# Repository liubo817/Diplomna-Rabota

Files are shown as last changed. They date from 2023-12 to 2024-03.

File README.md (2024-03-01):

# БОБКА - Био-Оптимизатор за Безопасна Костенуркова Атмосфера
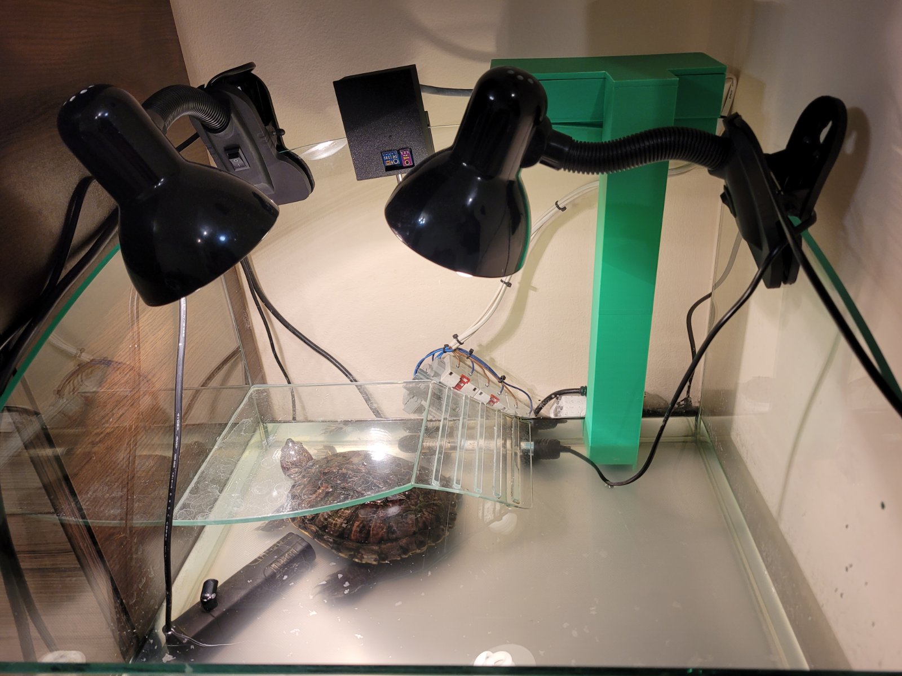
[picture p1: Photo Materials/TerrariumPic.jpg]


## **Описание**
Дипломната работа представя успешната разработка на вградена система, предназначена за наблюдение и управление на терариум за земноводни костенурки. Проектът обхваща иновативен хардуер и софтуер, които съчетават общоприети технологии.

## [Документация](https://docs.google.com/document/d/1n0dCljN07w4FLzlgteggXlk4XJQZPIcb2BojlvGgTRA/edit) ##

## **Създател:**
- **[Любомир Станев](https://github.com/liubo817)**

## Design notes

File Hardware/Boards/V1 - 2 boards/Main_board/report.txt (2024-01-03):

Info: Updated footprint U5 (Diplomna:5pin_holes): : (no changes)
Info: Updated footprint REF** (MountingHole:MountingHole_2.2mm_M2_DIN965_Pad_TopBottom): : (no changes)
Info: Updated footprint REF** (Resistor_SMD:R_0603_1608Metric_Pad0.98x0.95mm_HandSolder): : (no changes)
Info: Updated footprint REF** (Resistor_SMD:R_1206_3216Metric): : (no changes)
Info: Updated footprint REF** (Resistor_SMD:R_0603_1608Metric_Pad0.98x0.95mm_HandSolder): : (no changes)
Info: Updated footprint R1 (Resistor_SMD:R_1206_3216Metric): : (no changes)
Updated footprint U4 (Diplomna:light sensor): : OK
Updated footprint U3 (Diplomna:DS18B20_3dmodel): : OK
Updated footprint U2 (Diplomna:DS18B20_3dmodel): : OK
Info: Updated footprint REF** (Resistor_SMD:R_0603_1608Metric_Pad0.98x0.95mm_HandSolder): : (no changes)
Info: Updated footprint REF** (Package_TO_SOT_SMD:SOT-23): : (no changes)
Updated footprint U4 (Diplomna:DS18B20_3dmodel): : OK
Info: Updated footprint REF** (Resistor_SMD:R_0603_1608Metric_Pad0.98x0.95mm_HandSolder): : (no changes)
Updated footprint U1 (Diplomna:MODULE_ESP32-DEVKITC): : OK
Info: Updated footprint REF** (Diplomna:3pin_holes): : (no changes)
Info: Updated footprint REF** (MountingHole:MountingHole_2.2mm_M2_DIN965_Pad_TopBottom): : (no changes)
Updated footprint U4 (Diplomna:light sensor): : OK
Updated footprint U6 (Diplomna:DS18B20_3dmodel): : OK
Info: Updated footprint REF** (Resistor_SMD:R_0603_1608Metric_Pad0.98x0.95mm_HandSolder): : (no changes)

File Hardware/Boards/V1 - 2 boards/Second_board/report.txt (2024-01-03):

Info: Processing symbol 'J1:'.
Info: Processing symbol 'K1:EC2-5NU:RELAY_EC2-5NU'.
Info: Processing symbol 'R1:Resistor_SMD:R_1206_3216Metric'.
Info: Processing symbol 'U1:Diplomna:5pin_holes'.
Info: Processing symbol 'U2:Diplomna:light sensor'.
Info: Processing symbol 'U3:Diplomna:DS18B20_3dmodel'.
Warning: No net found for symbol U2 pin BASE.
Warning: No net found for symbol U2 pin COLLECTOR.
Warning: No net found for symbol U2 pin EMITTER.
Error: Cannot add J1 (no footprint assigned).
Error: Cannot add K1 (footprint 'EC2-5NU:RELAY_EC2-5NU' not found).
Error: U2 pad 3 not found in Diplomna:light sensor.
Error: U2 pad 2 not found in Diplomna:light sensor.
Error: U2 pad 1 not found in Diplomna:light sensor.

Info: Total warnings: 3, errors: 5.

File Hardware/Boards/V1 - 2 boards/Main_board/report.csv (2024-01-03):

Net Code | Net Name | Pad Count | Via Count | Via Length | Track Length | Die Length | Net Length | F.Cu | B.Cu
001 | +5V | 2 | 1 | 1.6000 mm | 36.9458 mm | 0.0000 mm | 38.5458 mm | 30.4289 mm | 6.5168 mm
002 | /Temp_out | 2 | 4 | 6.4000 mm | 106.2442 mm | 0.0000 mm | 112.6442 mm | 62.6944 mm | 43.5498 mm
003 | GND | 5 | 8 | 12.8000 mm | 158.6912 mm | 0.0000 mm | 171.4912 mm | 73.4497 mm | 85.2415 mm
004 | +3.3V | 4 | 2 | 3.2000 mm | 65.8150 mm | 0.0000 mm | 69.0150 mm | 8.3388 mm | 57.4762 mm
005 | /UV_out | 2 | 4 | 6.4000 mm | 91.8094 mm | 0.0000 mm | 98.2094 mm | 48.8913 mm | 42.9182 mm
006 | /Brightness_out | 2 | 4 | 6.4000 mm | 94.4588 mm | 0.0000 mm | 100.8588 mm | 51.4313 mm | 43.0275 mm
007 | /UV_ref | 2 | 3 | 4.8000 mm | 105.0883 mm | 0.0000 mm | 109.8883 mm | 61.1538 mm | 43.9345 mm
008 | /Water_temp_out | 3 | 3 | 4.8000 mm | 72.5599 mm | 0.0000 mm | 77.3599 mm | 26.5573 mm | 46.0026 mm
009 | /Turbidity_out | 2 | 0 | 0.0000 mm | 10.9145 mm | 0.0000 mm | 10.9145 mm | 0.0000 mm | 10.9145 mm
018 | /Water_level_out | 2 | 1 | 1.6000 mm | 80.7209 mm | 0.0000 mm | 82.3209 mm | 43.5137 mm | 37.2073 mm
040 | /Water_Level_Power | 2 | 3 | 4.8000 mm | 125.5482 mm | 0.0000 mm | 130.3482 mm | 65.5681 mm | 59.9801 mm

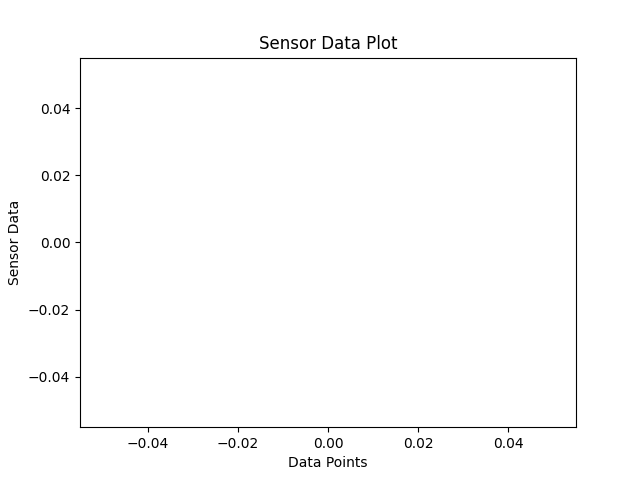
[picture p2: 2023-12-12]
Software/static/images/plot.png

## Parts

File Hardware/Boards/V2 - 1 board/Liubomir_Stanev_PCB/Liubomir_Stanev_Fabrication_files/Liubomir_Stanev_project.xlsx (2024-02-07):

Id | Designator | Footprint | Quantity | Designation
1 | U5 | 3pin_holes | 1 | DS18B20-water | ДА
2 | R1,R2 | R_Axial_DIN0309_L9.0mm_D3.2mm_P12.70mm_Horizontal | 2 | 2.2k | ДА
3 | J4,J5,J1,J2 | connector_3p | 4 | Conn_01x03_Pin | ?
4 | U2 | 3pin_holes | 1 | TEMT6000 | ДА
5 | U8 | connector_6p | 1 | Relay module | ДА
6 | U7 | MODULE_ESP32-DEVKITC | 1 | ESP32 | ДА
7 | J6,J3 | connector_2p | 2 | Conn_01x02_Pin | ДА
8 | U6 | 3pin_holes | 1 | Water Level Sensor | ДА
9 | U3 | 3pin_holes | 1 | DS18B20-air | ДА
10 | U4 | 3pin_holes | 1 | Turbidity sensor | ДА
11 | U1 | 5pin_holes | 1 | GY-8511 UV sensor | ДА
12 |  | Винтове за крепежни отвори | 4 | За сензора | НЕ
13 |  | Винтове за крепежни отвори | 8 | За платките | НЕ

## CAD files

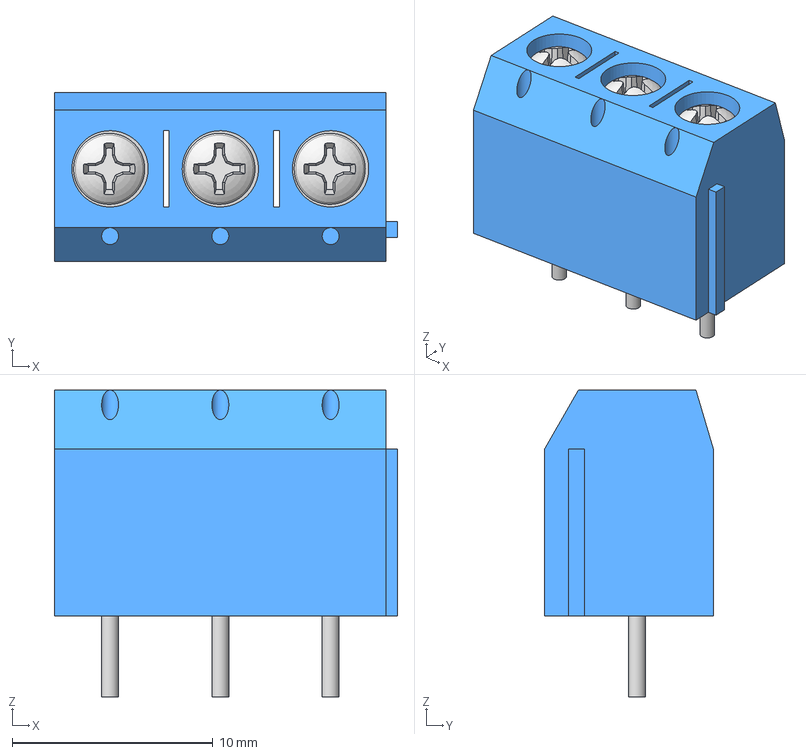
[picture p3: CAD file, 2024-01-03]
Hardware/Libraries and 3D models/3p_con/connector_3p v2.step
17.1 x 8.41 x 15.3 mm

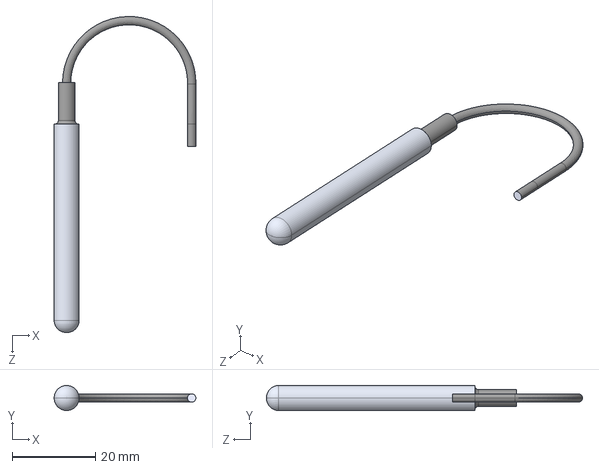
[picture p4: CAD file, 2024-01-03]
Hardware/Libraries and 3D models/Ds18B20/ds18b20.STEP
34.0 x 6.00 x 75.8 mm

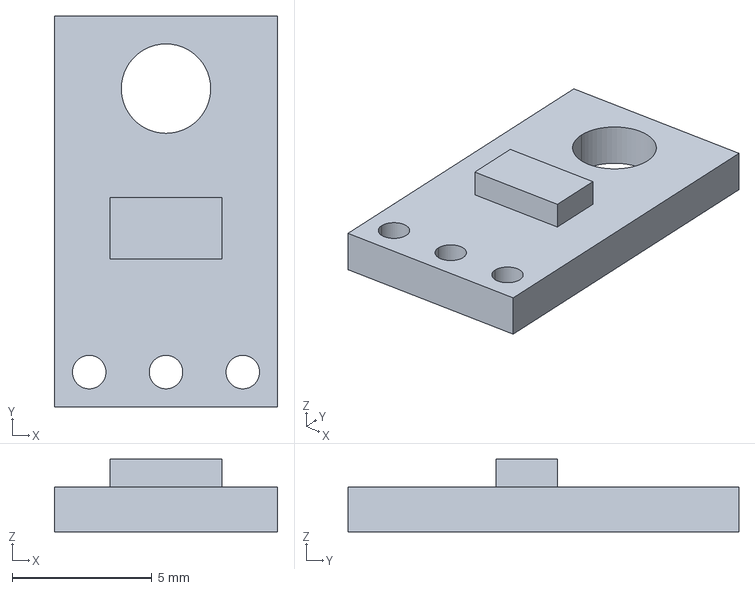
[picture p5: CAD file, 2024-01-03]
Hardware/Libraries and 3D models/Light_Sensor/TEMT6000.stp
8.00 x 14.0 x 2.60 mm

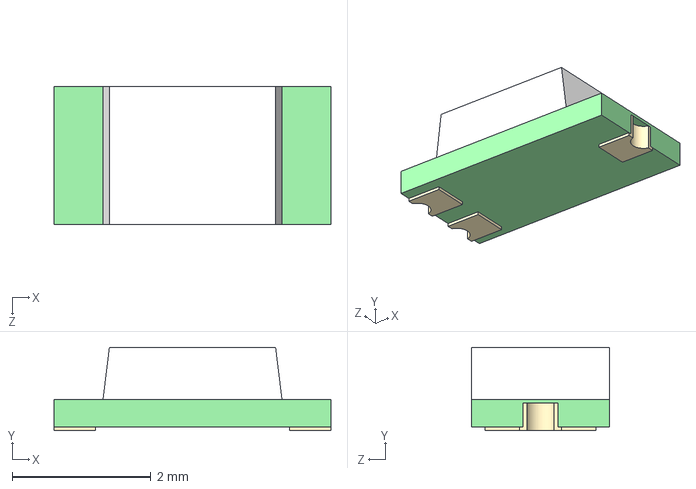
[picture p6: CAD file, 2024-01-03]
Hardware/Libraries and 3D models/TEMT6000/TEMT6000X01--3DModel-STEP-56544.STEP
4.00 x 1.20 x 2.00 mm

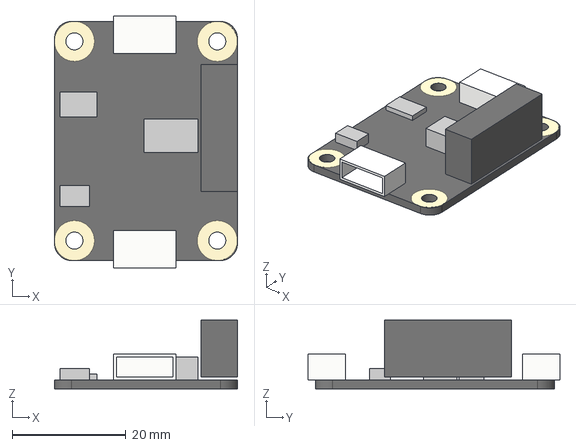
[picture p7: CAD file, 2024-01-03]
Hardware/Libraries and 3D models/Turbidity_sensor/Analog Isolator DF Robot v1.step
32.1 x 44.3 x 12.1 mm

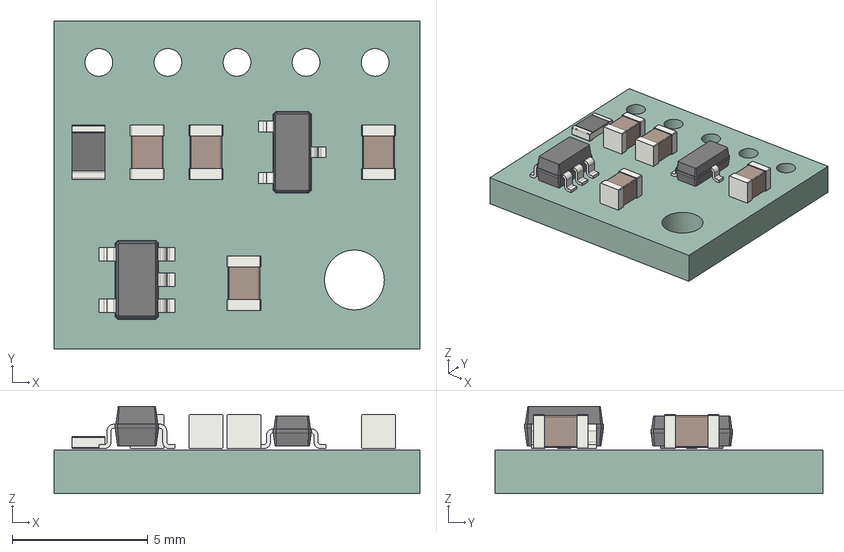
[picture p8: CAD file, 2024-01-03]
Hardware/Libraries and 3D models/UV/uv.step
13.5 x 12.1 x 3.20 mm
uv PCB

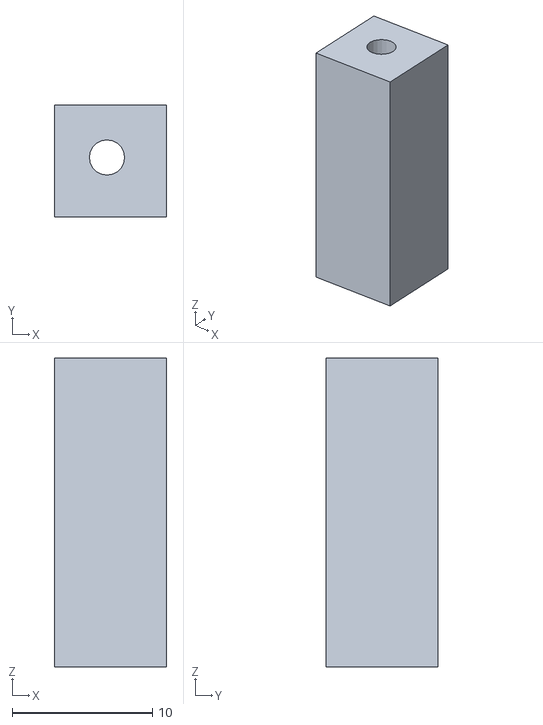
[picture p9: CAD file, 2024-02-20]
Mechanical details/Dist.vtulka.stl
8.00 x 8.00 x 22.0

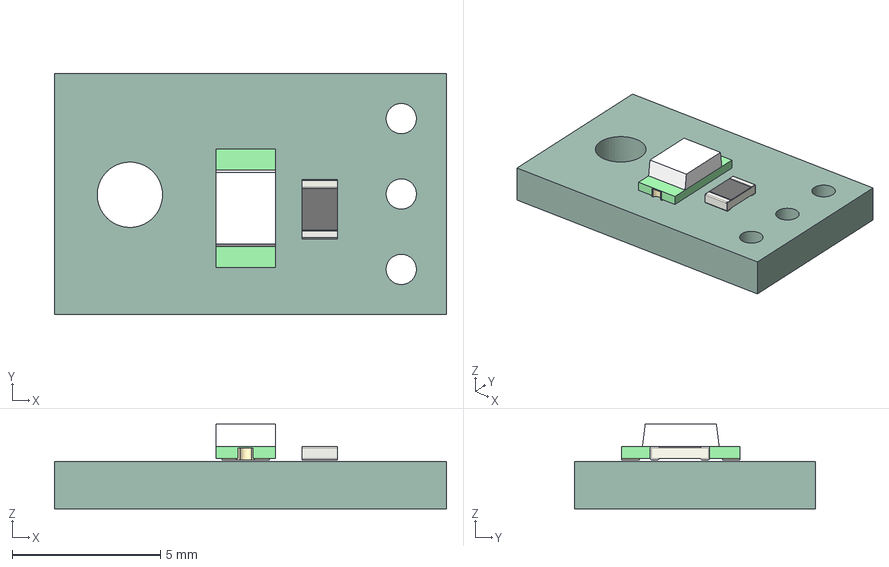
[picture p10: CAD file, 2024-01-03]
Hardware/Libraries and 3D models/TEMT6000/temt6000.step
13.2 x 8.13 x 2.85 mm
temt6000 PCB

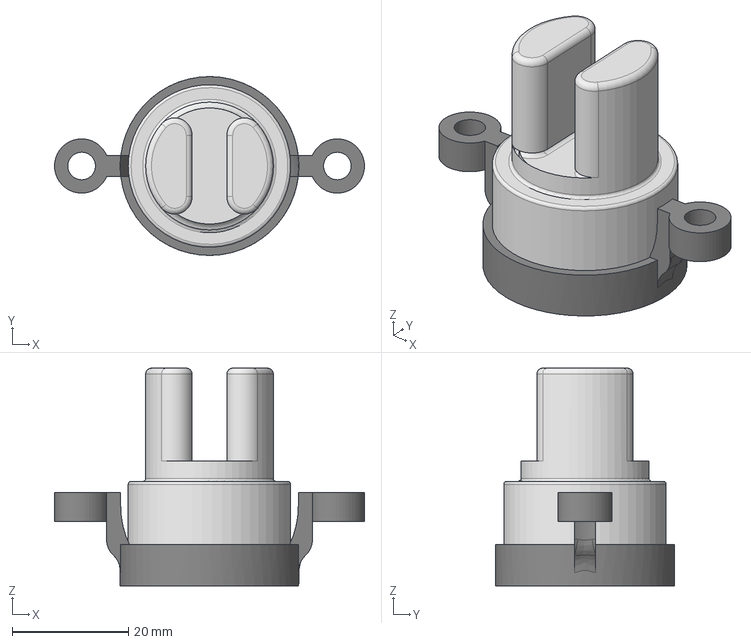
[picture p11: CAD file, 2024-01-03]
Hardware/Libraries and 3D models/Turbidity_sensor/Turbidity Sensor v1.step
53.4 x 30.8 x 37.5 mm

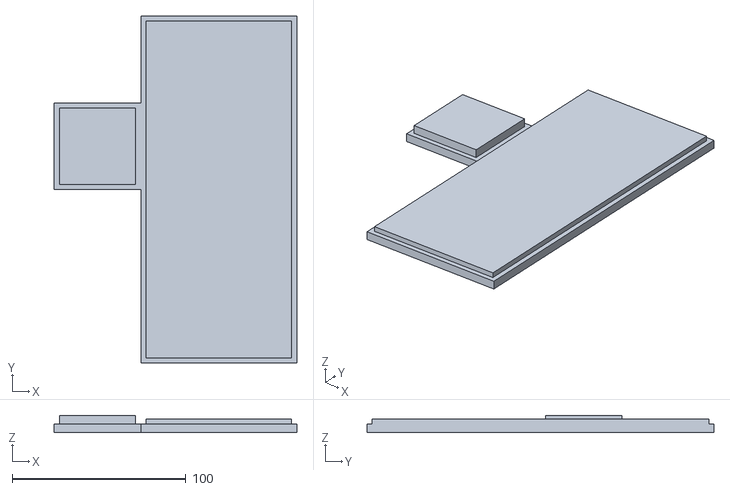
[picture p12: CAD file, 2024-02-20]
Mechanical details/TopSide_BigBox.stl
140.0 x 200.0 x 10.0

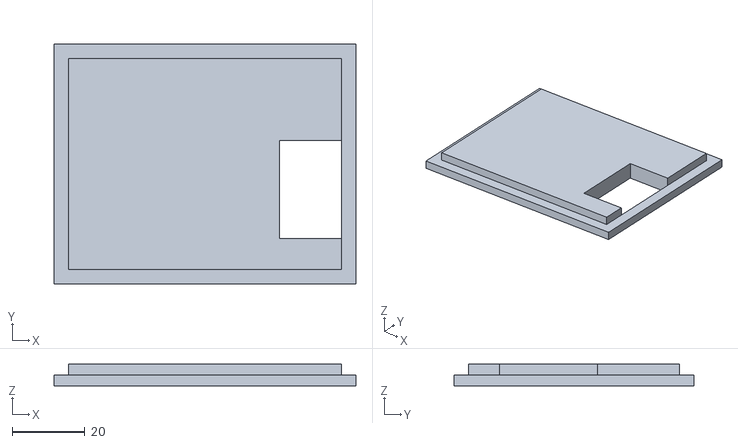
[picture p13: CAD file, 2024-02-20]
Mechanical details/TopSide_SmallBox.stl
83.0 x 66.0 x 6.00

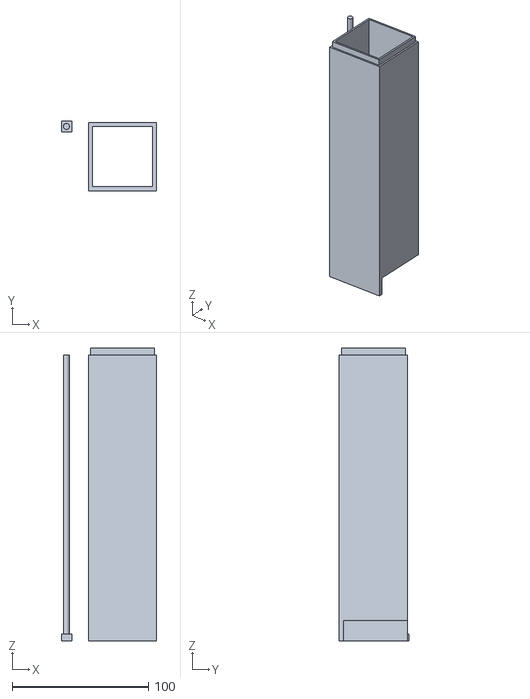
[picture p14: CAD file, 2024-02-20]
Mechanical details/Kolona2.stl
70.0 x 51.0 x 215.0

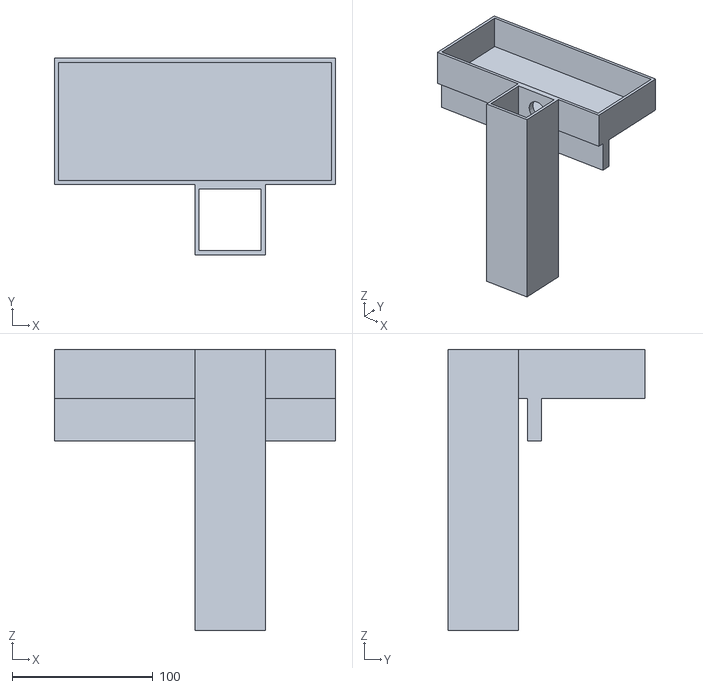
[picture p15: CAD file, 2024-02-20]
Mechanical details/BigBox.stl
200.0 x 140.0 x 200.0

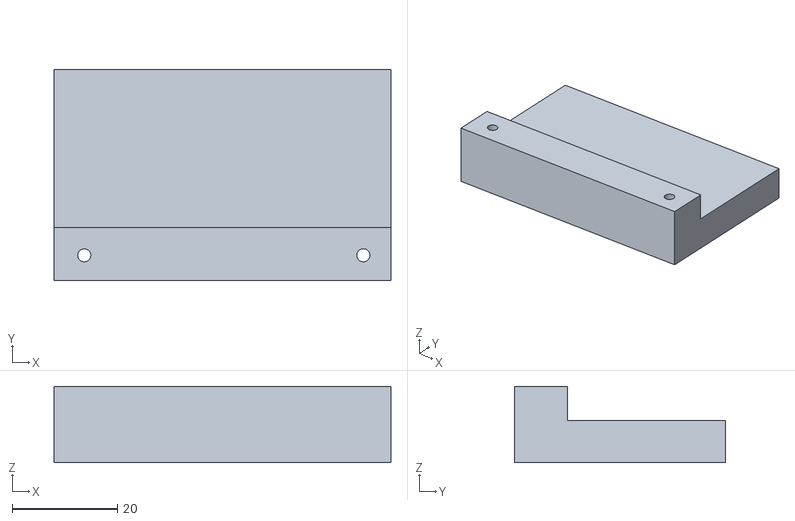
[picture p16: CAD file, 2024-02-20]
Mechanical details/G-figure.stl
64.0 x 40.0 x 14.5

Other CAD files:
Mechanical details/SmallBox.stl
Hardware/Libraries and 3D models/3p_con/connector_3p v1.step
Hardware/Libraries and 3D models/3p_con/connector_3p v1.f3d

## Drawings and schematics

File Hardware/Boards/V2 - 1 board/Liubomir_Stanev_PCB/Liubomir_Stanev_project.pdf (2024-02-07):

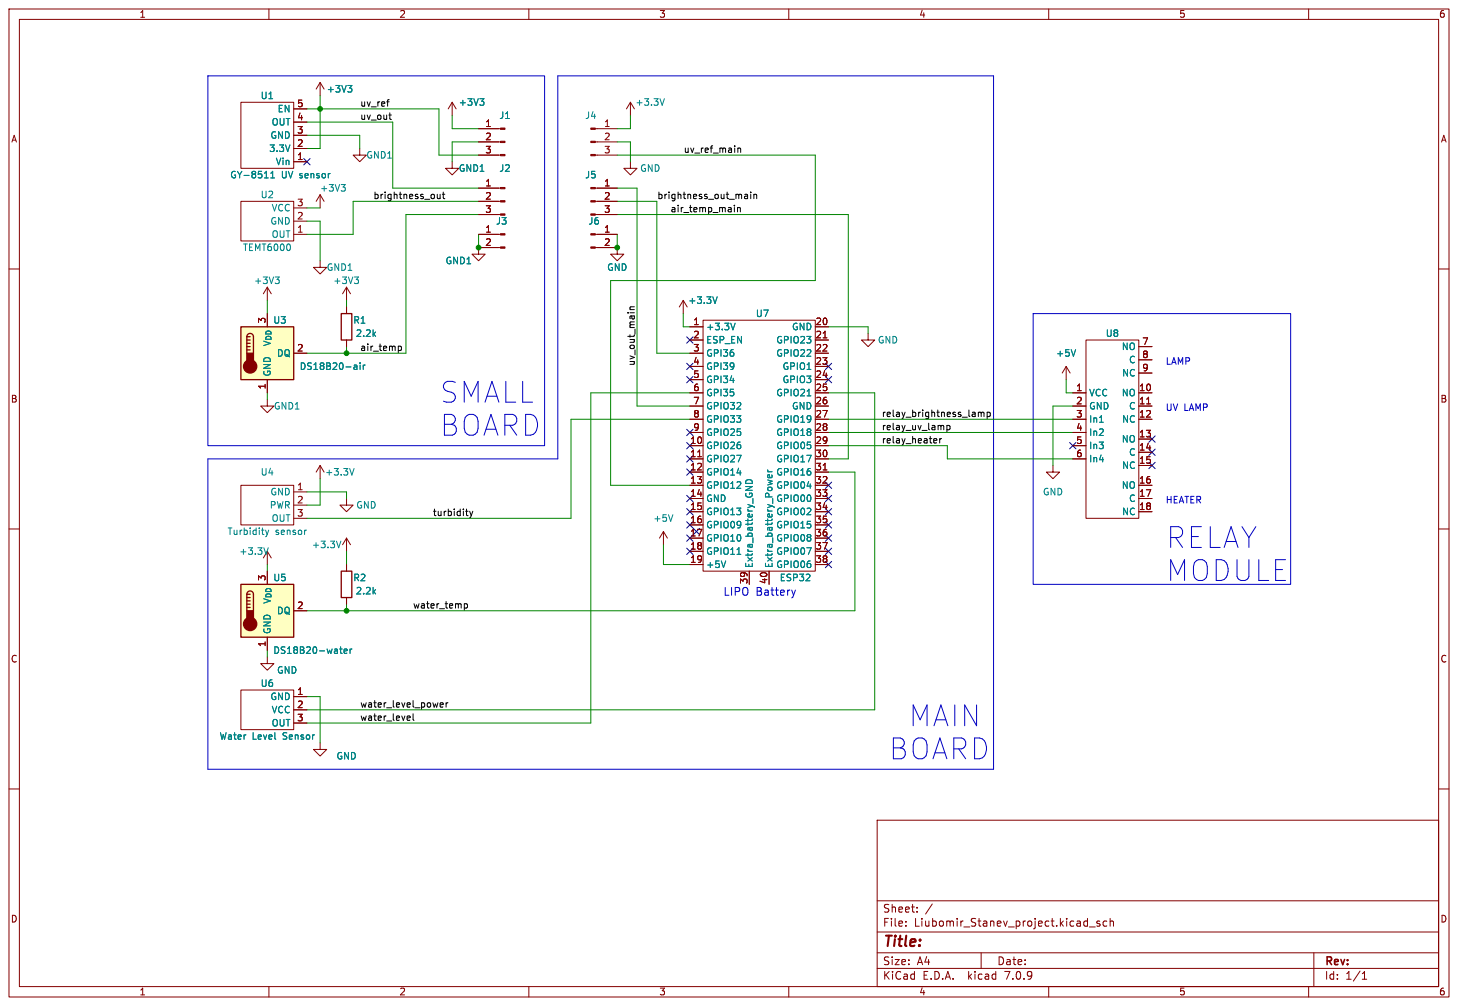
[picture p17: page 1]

Id: 1/1 Title: File: Liubomir_Stanev_project.kicad_sch Sheet: /

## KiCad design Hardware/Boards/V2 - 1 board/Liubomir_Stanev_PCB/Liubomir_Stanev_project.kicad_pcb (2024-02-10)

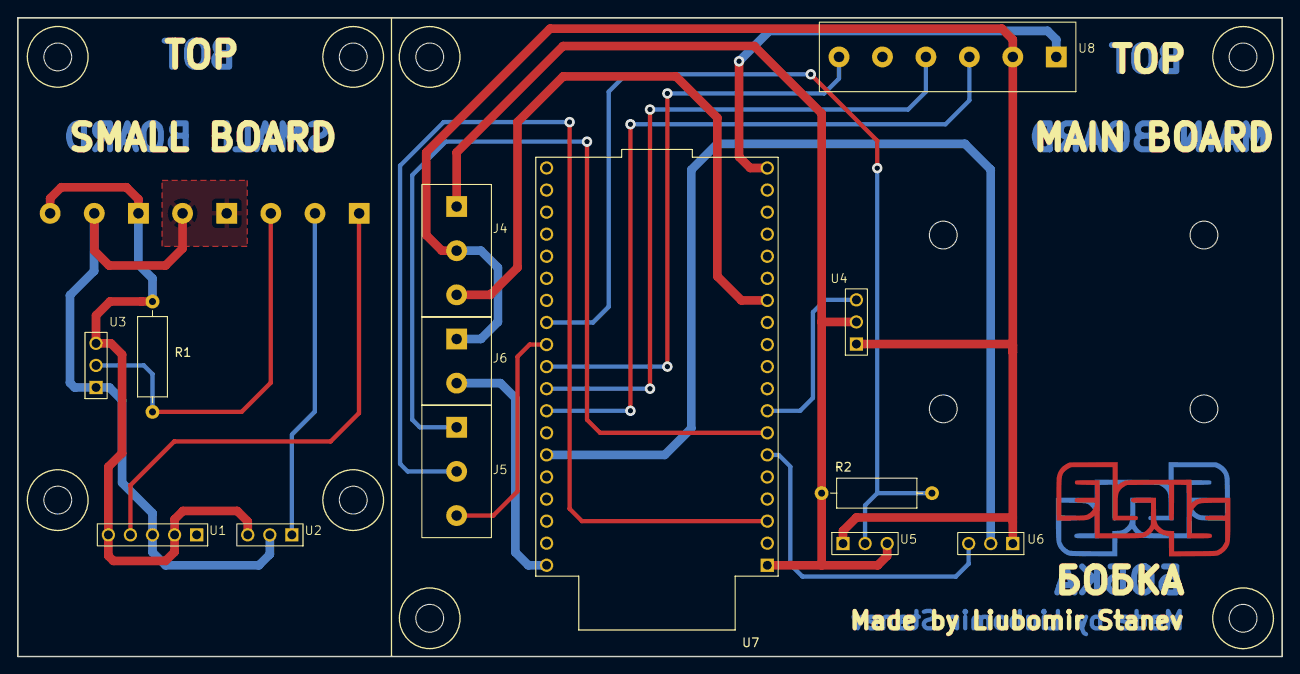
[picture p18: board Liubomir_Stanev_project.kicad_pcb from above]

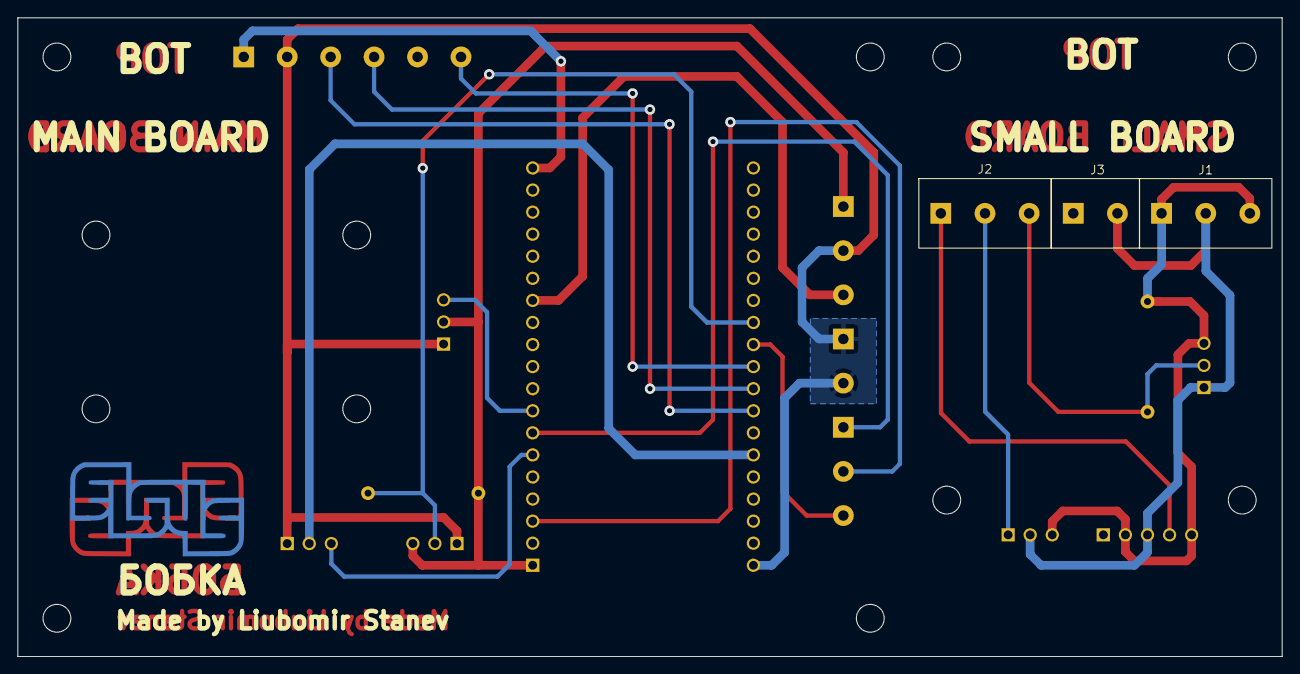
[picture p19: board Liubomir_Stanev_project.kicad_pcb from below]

Board: 2 copper layers, 145.5 x 73.5 mm, 16 parts (3 on the bottom side), 19 nets.

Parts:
J1, J2, J4, J5: Conn_01x03_Pin; connector_3p
J3, J6: Conn_01x02_Pin; connector_2p
R1, R2: 2.2k; R_Axial_DIN0309_L9.0mm_D3.2mm_P12.70mm_Horizontal
U1: GY-8511 UV sensor; 5pin_holes
U2: TEMT6000; 3pin_holes
U3: DS18B20-air; 3pin_holes
U4: Turbidity sensor; 3pin_holes
U5: DS18B20-water; 3pin_holes
U6: Water Level Sensor; 3pin_holes
U7: ESP32; MODULE_ESP32-DEVKITC
U8: Relay module; connector_6p

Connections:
+3.3V: J4.1, R2.1, U4.2 (PWR), U5.3 (V_{DD}), U7.1 (+3.3V)
+3V3: J1.1, J1.3, R1.1, U1.2 (3.3V), U1.5 (EN), U2.3 (VCC), U3.3 (V_{DD})
+5V: U7.19 (+5V), U8.1 (VCC)
/air_temp: J2.3, R1.2, U3.2 (DQ)
/air_temp_main: J5.3, U7.30 (GPIO17)
/brightness_out: J2.2, U2.1 (OUT)
/brightness_out_main: J5.2, U7.3 (GPI36)
/relay_brightness_lamp: U7.27 (GPIO19), U8.3 (In1)
/relay_heater: U7.29 (GPIO05), U8.6 (In4)
/relay_uv_lamp: U7.28 (GPIO18), U8.4 (In2)
/turbidity: U4.3 (OUT), U7.8 (GPIO33)
/uv_out: J2.1, U1.4 (OUT)
/uv_out_main: J5.1, U7.7 (GPIO32)
/uv_ref_main: J4.3, U7.13 (GPIO12)
/water_level: U6.3 (OUT), U7.6 (GPI35)
/water_level_power: U6.2 (VCC), U7.25 (GPIO21)
/water_temp: R2.2, U5.2 (DQ), U7.31 (GPIO16)
GND: J4.2, J6.1, J6.2, U4.1 (GND), U5.1 (GND), U6.1 (GND), U7.20 (GND), U8.2 (GND)
GND1: J1.2, J3.1, J3.2, U1.3 (GND), U2.2 (GND), U3.1 (GND)

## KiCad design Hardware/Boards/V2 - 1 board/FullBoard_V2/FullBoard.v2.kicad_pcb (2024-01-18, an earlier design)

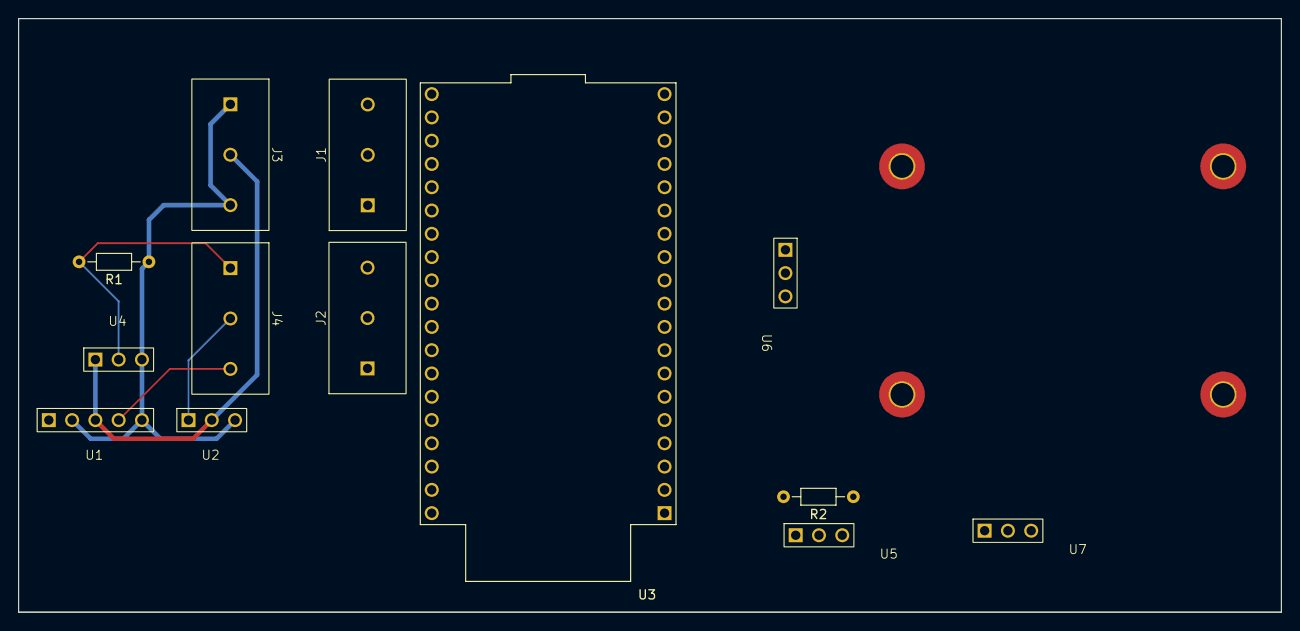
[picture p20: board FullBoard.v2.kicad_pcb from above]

Board: 2 copper layers, 137.8 x 64.8 mm, 14 parts (0 on the bottom side), 15 nets.

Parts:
J1, J2, J3, J4: Conn_01x03_Pin; connector_3p
K1: Relay_SPDT; Relay
R1, R2: 2.2k; R_Axial_DIN0204_L3.6mm_D1.6mm_P7.62mm_Horizontal
U1: GY-8511 UV sensor; 5pin_holes
U2: TEMT6000; 3pin_holes
U3: MODULE_ESP32-DEVKITC
U4: DS18B20-air; DS18B20_3dmodel
U5: DS18B20-water; DS18B20_3dmodel
U6: Turbidity sensor; 3pin_holes
U7: Water Level; 3pin_holes

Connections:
+3.3V: J1.1, R2.1, U3.1 (+3.3V), U5.3 (V_{DD}), U6.1 (PWR)
+3V3: J3.1, J3.3, R1.1, U1.2 (3.3V), U1.5 (EN), U2.3 (VCC), U4.3 (V_{DD})
/air_temp: J4.1, R1.2, U4.2 (DQ)
/air_temp_main: J2.1, U3.6 (GPI35)
/brightness_out: J4.2, U2.1 (OUT)
/brightness_out_main: J2.2, U3.3 (GPI36)
/turbidity: U3.8 (GPIO33), U6.3 (OUT)
/uv_out: J4.3, U1.4 (OUT)
/uv_out_main: J2.3, U3.7 (GPIO32)
/uv_ref_main: J1.3, U3.13 (GPIO12)
/water_level: U3.15 (GPIO13), U7.3 (OUT)
/water_level_power: U3.25 (GPIO21), U7.2 (VCC)
/water_temp: R2.2, U3.32 (GPIO04), U5.2 (DQ)
GND: J1.2, U3.20 (GND), U5.1 (GND), U6.2 (GND), U7.1 (GND)
GND1: J3.2, U1.3 (GND), U2.2 (GND), U4.1 (GND)

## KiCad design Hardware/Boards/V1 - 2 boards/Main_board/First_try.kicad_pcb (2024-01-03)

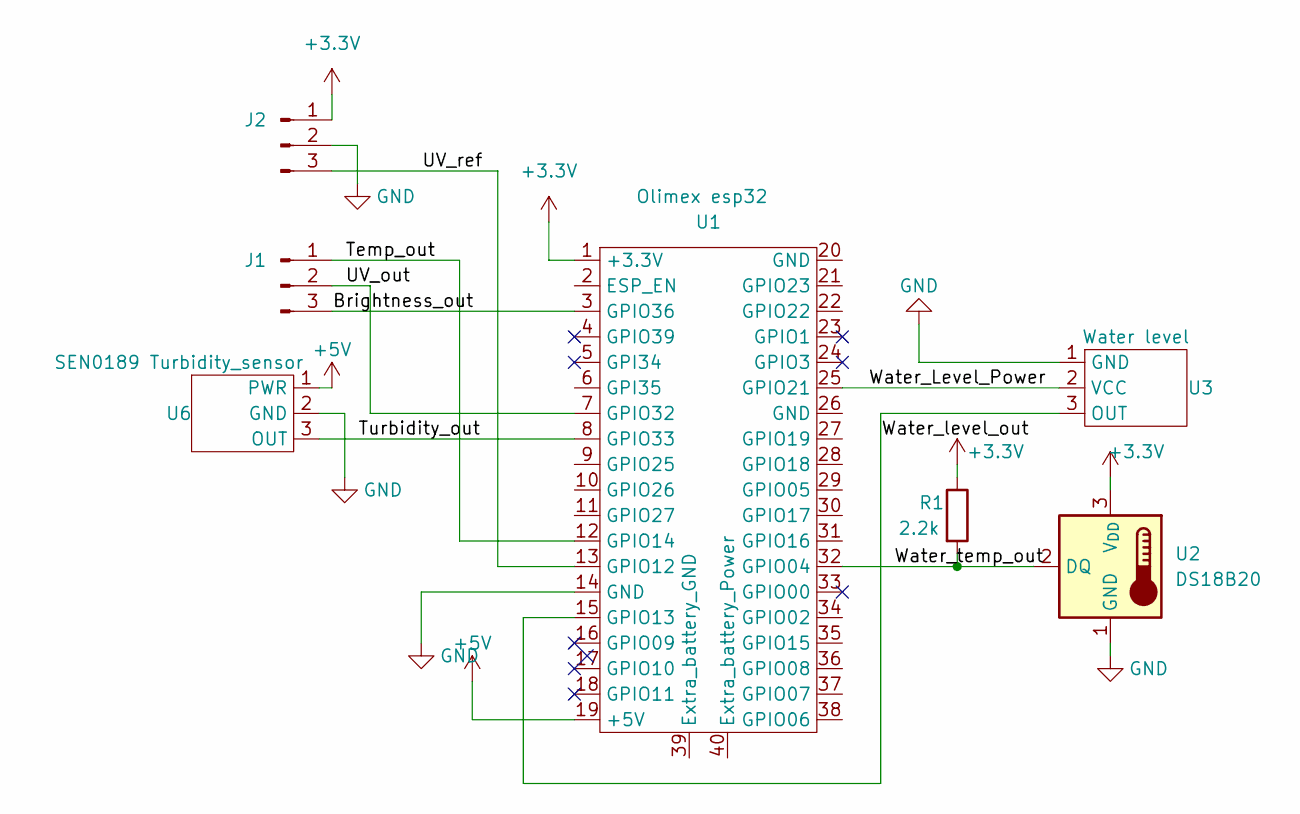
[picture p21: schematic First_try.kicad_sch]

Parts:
J1, J2: Conn_01x03_Pin; connector_3p
R1: 2.2k; R_Axial_DIN0204_L3.6mm_D1.6mm_P7.62mm_Horizontal
U1: Olimex esp32; MODULE_ESP32-DEVKITC
U2: DS18B20; DS18B20_3dmodel
U3: Water level; DS18B20_3dmodel
U6: SEN0189 Turbidity_sensor; DS18B20_3dmodel

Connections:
+3.3V: J2.1, R1.1, U1.1 (+3.3V), U2.3 (V_{DD})
+5V: U1.19 (+5V), U6.1 (PWR)
/Brightness_out: J1.3, U1.3 (GPIO36)
/Temp_out: J1.1, U1.12 (GPIO14)
/Turbidity_out: U1.8 (GPIO33), U6.3 (OUT)
/UV_out: J1.2, U1.7 (GPIO32)
/UV_ref: J2.3, U1.13 (GPIO12)
/Water_Level_Power: U1.25 (GPIO21), U3.2 (VCC)
/Water_level_out: U1.15 (GPIO13), U3.3 (OUT)
/Water_temp_out: R1.2, U1.32 (GPIO04), U2.2 (DQ)
GND: J2.2, U1.14 (GND), U2.1 (GND), U3.1 (GND), U6.2 (GND)

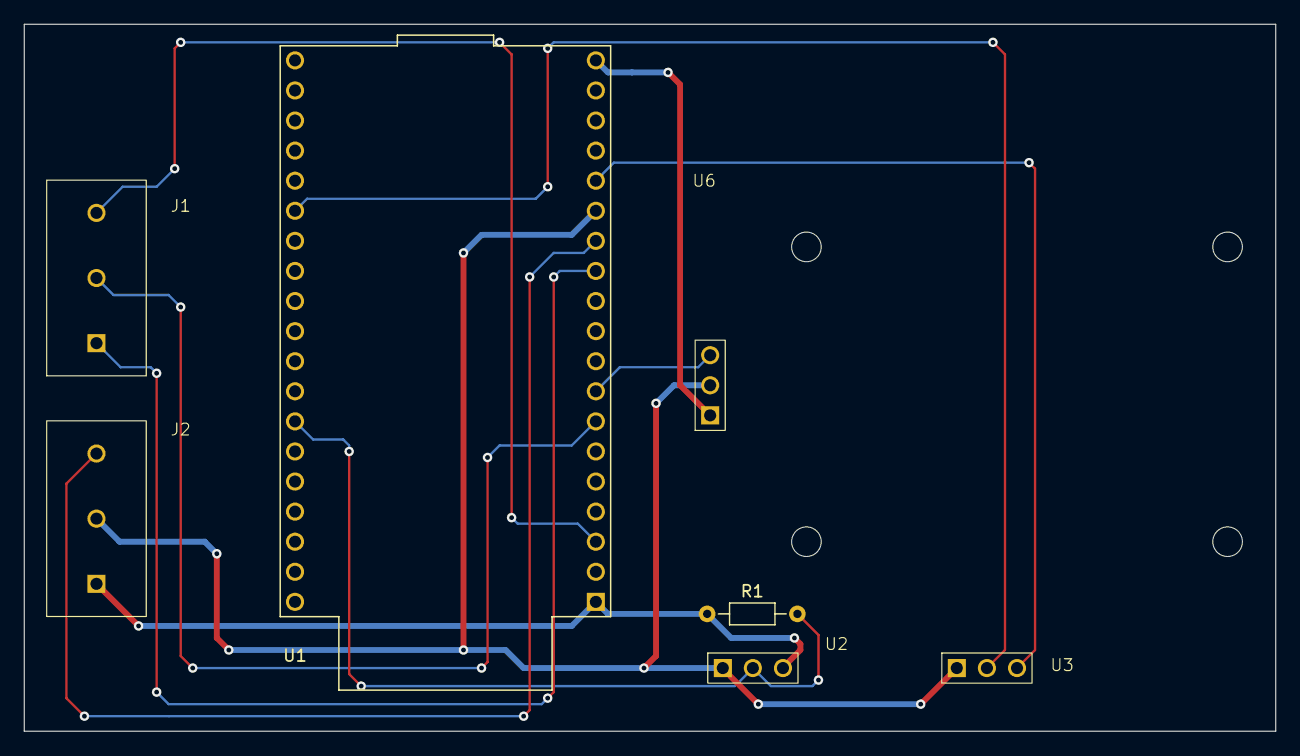
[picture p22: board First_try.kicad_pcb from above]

Board: 2 copper layers, 105.7 x 59.7 mm, 7 parts (0 on the bottom side), 11 nets.

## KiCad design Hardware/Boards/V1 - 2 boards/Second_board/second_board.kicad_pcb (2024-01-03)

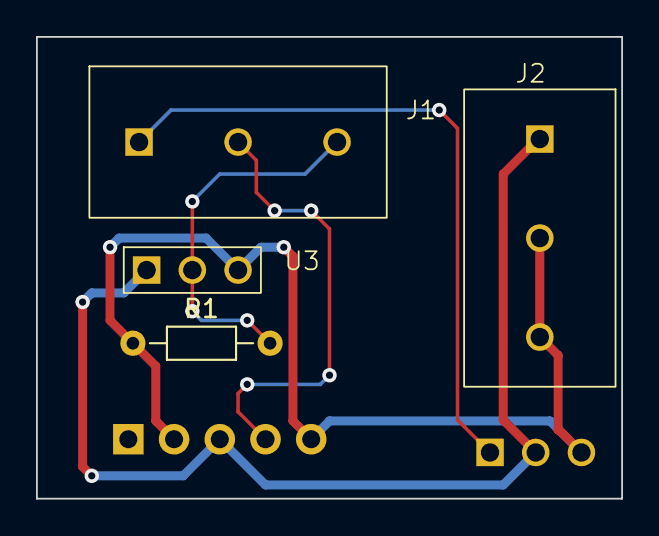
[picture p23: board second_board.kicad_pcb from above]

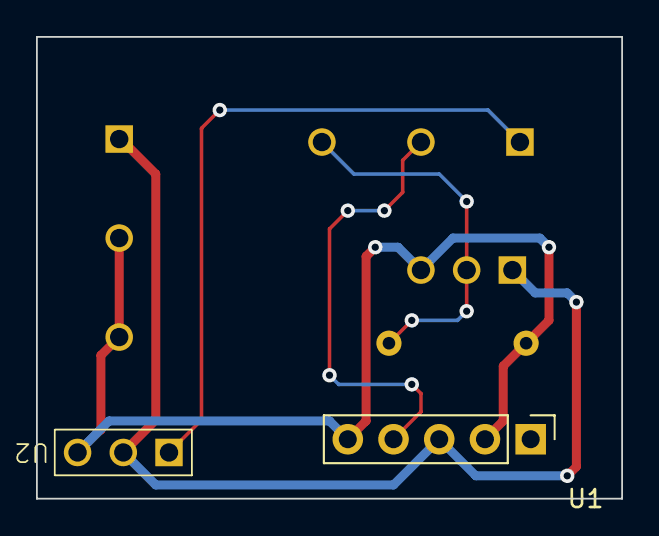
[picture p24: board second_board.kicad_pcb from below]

Board: 2 copper layers, 32.5 x 25.7 mm, 6 parts (2 on the bottom side), 5 nets.

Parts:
J1, J2: Conn_01x03_Pin; connector_3p
R1: 2.2k; R_Axial_DIN0204_L3.6mm_D1.6mm_P7.62mm_Horizontal
U1: GY-8511 UV sensor; PinHeader_1x05_P2.54mm_Vertical
U2: TEMT6000; 3pin_holes
U3: DS18B20; DS18B20_3dmodel

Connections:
+3.3V: J2.2, J2.3, R1.1, U1.2 (3.3V), U1.5 (EN), U2.3 (VCC), U3.3 (V_{DD})
/BRIGHTNESS_OUT: J1.1, U2.1 (OUT)
/TEMPERATURE_OUT: J1.3, R1.2, U3.2 (DQ)
/UV_OUT: J1.2, U1.4 (OUT)
GND: J2.1, U1.3 (GND), U2.2 (GND), U3.1 (GND)

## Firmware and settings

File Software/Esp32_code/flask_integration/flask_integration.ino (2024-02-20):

#include <math.h>
#include <OneWire.h>
#include <DallasTemperature.h>
#include <WiFi.h>
#include <HTTPClient.h>

#define ds18b20WaterPin 16
#define ds18b20Pin 17
#define uvPin 32
#define turbidityPin 33
#define waterLevelPin 35
#define brightnessPin 36
#define relayLamp 19
#define relayUV 18
#define relayHeater 5
#define waterLevelSensorPower 21


bool auto_mode = false;
const float minLogValue = 2.5;  
const float maxLogValue = 10.0;

const char* ssid = ""; //YourWiFiSSID
const char* password = ""; //YourWiFiPassword
const char* serverAddress = "http://192.168.100.10:5000/receive_data";
const int serverPort = 80;


WiFiServer server(serverPort);

OneWire oneWire(ds18b20WaterPin);	
DallasTemperature ds18b20_water(&oneWire);

OneWire oneWireAir(ds18b20Pin);	
DallasTemperature ds18b20(&oneWireAir);

void sendSensorData(const char* sensorType, float data, const char* measuringUnit) {
  
  HTTPClient http;
  
  if (WiFi.status() == WL_CONNECTED) // Check if WiFi is connected
  {
    http.begin(serverAddress); // Your Flask server endpoint
    http.addHeader("Content-Type", "application/json"); // Specify content type
    
    String jsonData = "{\"sensorType\":\"" + String(sensorType) + "\",\"sensorData\":" + String(data) + ",\"measuringUnit\":\"" + String(measuringUnit) + "\"}"; // Create JSON payload
    int httpResponseCode = http.POST(jsonData); // Send the POST request
    

    if (httpResponseCode > 0) // Check for errors
    {
      Serial.print("HTTP Response code: ");
      Serial.println(httpResponseCode);
    } else {
      Serial.print("HTTP Error: ");
      Serial.println(httpResponseCode);
    }

    http.end();
  } else {
    Serial.println("WiFi not connected. Skipping HTTP request.");
  }
}




float mapfloat(float x, float in_min, float in_max, float out_min, float out_max)
{
  return (x - in_min) * (out_max - out_min) / (in_max - in_min) + out_min;
}

float scaleToLogarithmic(int sensorReading)
{
  float scaledValue = map(sensorReading, 0, 4095, minLogValue * 1000, maxLogValue * 1000) / 1000.0;
  return log10(scaledValue);
}

int turbidity()
{
  int turbidityPercentage;
  int turbidityValue = analogRead(turbidityPin);
  float logarithmicTurbidity = scaleToLogarithmic(turbidityValue);
  turbidityPercentage = map(turbidityValue, 2350, 1750, 0, 100);
  Serial.println(turbidityValue);
  //return turbidityValue;
  return turbidityPercentage;
}


float waterTemp()
{
  ds18b20_water.requestTemperatures();
  delay(750);
  float temperatureC = ds18b20_water.getTempCByIndex(0);
  return temperatureC;
}

float airTemp()
{
  ds18b20.requestTemperatures();
  delay(750);
  float temperatureC = ds18b20.getTempCByIndex(0);
  return temperatureC;
}



float waterLevel()
{
  int waterLevel;
  float waterLevelPercentage;
  waterLevel = analogRead(waterLevelPin);
	digitalWrite(waterLevelSensorPower, HIGH);
	delay(10);
	digitalWrite(waterLevelSensorPower, LOW);
  waterLevelPercentage = map(waterLevel, 555, 1670, 0, 100);
  return waterLevel;
	return waterLevelPercentage;
}


float UVlevel()
{
  int uvLevel = analogRead(uvPin);
  float outputVoltage = uvLevel * (3.3 / 4095);
  float uvIntensity = mapfloat(outputVoltage, 0.99, 2.8, 0.0, 15.0); //Convert voltage to UV intensity
  return uvIntensity;
}

int brightness()
{
  int brightnessLevel = analogRead(brightnessPin);
  int brightnessLux;
  brightnessLux = map(brightnessLevel, 0, 4095, 10, 1000);
  return brightnessLux;
}



void setup(void)
{
  pinMode(waterLevelSensorPower, OUTPUT);
  pinMode(uvPin, INPUT);
  pinMode(waterLevelPin, INPUT);
  pinMode(relayLamp, OUTPUT);
  pinMode(relayUV, OUTPUT);
  pinMode(relayHeater, OUTPUT);

  Serial.begin(9600);
  WiFi.begin(ssid, password);
  ds18b20_water.begin();
  ds18b20.begin();

  while (WiFi.status() != WL_CONNECTED) {
    delay(1000);
    Serial.println("Connecting to WiFi...");
  }
  Serial.println("Connected to WiFi");
  Serial.print("ESP32 IP Address: ");
  Serial.println(WiFi.localIP());
  server.begin(); //Start the server
  Serial.println("Server started");
}


void loop()
{
  static unsigned long lastUpdateTime = 0;
  const unsigned long updateInterval = 5000; // Update every 5 seconds

  WiFiClient client = server.available();

  if (client) {
    String request = client.readStringUntil('\r');
    Serial.println("Received request: " + request);

    if (request.indexOf("set_auto_mode") != -1) {
      if (request.indexOf("state=ON") != -1) {
        auto_mode = true;
        Serial.println("Auto Mode turned ON");
          
    
      } else if (request.indexOf("state=OFF") != -1) {
        auto_mode = false;
        Serial.println("Auto Mode turned OFF");
      }
    } else {
      if (request.indexOf("state=ON") != -1) {
        if (request.indexOf("device_type=LAMP") != -1) {
          digitalWrite(relayLamp, HIGH);
          auto_mode = false;
          Serial.println("Turning ON the LAMP");
        } else if (request.indexOf("device_type=UV_LAMP") != -1) {
          digitalWrite(relayUV, HIGH);
          auto_mode = false;         
          Serial.println("Turning ON the UV LAMP");
        } else if (request.indexOf("device_type=HEATER") != -1) {
          digitalWrite(relayHeater, HIGH);
          auto_mode = false;
          Serial.println("Turning ON the HEATER");
        }
      } else if (request.indexOf("state=OFF") != -1) {
        if (request.indexOf("device_type=LAMP") != -1) {
          digitalWrite(relayLamp, LOW);
          auto_mode = false;
          Serial.println("Turning OFF the LAMP");
        } else if (request.indexOf("device_type=UV_LAMP") != -1) {
          digitalWrite(relayUV, LOW);
          auto_mode = false;
          Serial.println("Turning OFF the UV LAMP");
        } else if (request.indexOf("device_type=HEATER") != -1) {
          digitalWrite(relayHeater, LOW);
          auto_mode = false;
          Serial.println("Turning OFF the HEATER");
        }
      }
    }
  }

    if(auto_mode == true)
    {
      if (waterTemp() < 24)
        {
          digitalWrite(relayHeater, HIGH);
        }
        else if (waterTemp() > 30)
        {
          digitalWrite(relayHeater, LOW);
        }

        if (brightness() < 70)
        {
          digitalWrite(relayLamp, HIGH);
        }
        else if (brightness() > 95)
        {
          digitalWrite(relayLamp, LOW);
        }

        if (UVlevel() <= 0.5)
        {
          digitalWrite(relayUV, HIGH);
        }
        else if (UVlevel() > 1.5)
        {
          digitalWrite(relayUV, LOW);
        }
    }


  unsigned long currentMillis = millis();


  if (currentMillis - lastUpdateTime >= updateInterval) {

    Serial.println(waterTemp());
    Serial.println(airTemp());
    Serial.println(UVlevel());
    Serial.println(brightness());
    Serial.println(waterLevel());
    Serial.println(turbidity());
    //Send sensor data to the server
    sendSensorData("Water Temp", waterTemp(), "Celsius");
    sendSensorData("Turbidity", turbidity(), "Percentage");
    sendSensorData("Air Temp", airTemp(), "Celsius");
    sendSensorData("UV Level", UVlevel(), "UV intensity mW/cm2");
    sendSensorData("Brightness Level", brightness(), "Lux");
    sendSensorData("Water Level", waterLevel(), "Celsius");
    lastUpdateTime = currentMillis;
  }

}

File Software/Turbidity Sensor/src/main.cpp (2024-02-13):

#include <Arduino.h>
#include "CQRobotTDS.h"


int sensorPin = 33;

CQRobotTDS tds(sensorPin);
unsigned long timeout = 0;

void setup()
{ 
  Serial.begin(9600);

}
void loop() {
  float temp = 25.0; // read temprature from a real sensor
	float tdsValue = tds.update(temp);

	if (timeout<millis())
	{
		Serial.print("TDS value: ");
		Serial.print(tdsValue, 0);
		Serial.println(" ppm");
		timeout=millis() + 1000;
	}

  /*int sensorValue = analogRead(sensorPin);
  //Serial.println(sensorValue);
  int turbidity = map(sensorValue, 0, 4095, 0, 100);
  int clean = map(turbidity, 0, 100, 100, 0);
  delay(300);
  // Serial.println("Turbidity: ");
  // Serial.print(turbidity);
  // Serial.print("%");
  // delay(500);
  Serial.print("Cleanliness: ");
  Serial.print(clean);
  Serial.println("%");*/
}

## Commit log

2023-11-11 Tested the water level sensor
2023-11-11 Added percantages to the water level sensor as well as working with a LED
2023-11-21 Tested temperature sensor ds18b20 in water - working properly
2023-12-07 Tested the turbidity sensor
2023-12-07 The 3 sensors for the water were tested together
2023-12-12 Semi-working connection between sensor data and a flask web server
2023-12-12 Working connection between Flask webserver and temperarture sensor
2023-12-19 Displaying data from the temperature sensor on the flask webpage in real time
2023-12-23 Tested the UV sensor
2023-12-24 Every sensor has its own function
2023-12-24 Every sensor on a different graph
2024-01-03 Added schemes
    [Analog Isolator DF Robot v1.step, First_try.kicad_pcb, First_try.kicad_sch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]
2024-01-07 Made two main folders and added a full scheme
    [Analog Isolator DF Robot v1.step, First_try.kicad_pcb, First_try.kicad_sch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]
2024-01-09 Tested the logic from the Flask webpage to the ESP32 with LED
2024-01-09 The full board combined
    [FullBoard.kicad_pcb]
2024-01-10 Second version of the full board
    [FullBoard.kicad_pcb, FullBoard.kicad_sch]
2024-01-18 Almost completed scheme
    [FullBoard.kicad_pcb, FullBoard.kicad_sch, FullBoard.v2.kicad_pcb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]
2024-02-01 Scheme and board completed as well as relay module tested
    [First_try.kicad_pcb, First_try.kicad_sch, FullBoard.kicad_pcb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]
2024-02-03 PCB almost complete
    [FullBoard.kicad_pcb, FullBoard.kicad_sch]
2024-02-03 Added names on silkscreen and moved some of the connectors
    [FullBoard.kicad_pcb]
2024-02-03 Combined flask integration and flask to esp32 in the integration code (Working with home WiFi)
2024-02-03 PCB complete
    [FullBoard.kicad_pcb]
2024-02-03 Fabrication files ready
    [Liubomir_Stanev_PCB-B_Courtyard.gbr, Liubomir_Stanev_PCB-B_Cu.gbr, Liubomir_Stanev_PCB-B_Fab.gbr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]
2024-02-04 Added testing for 3 relays and updated flask app
2024-02-04 Fixed some issues on the board and addded some logic for the turbidity sensor
    [Liubomir_Stanev_PCB-B_Courtyard.gbr, Liubomir_Stanev_PCB-F_Courtyard.gbr, Liubomir_Stanev_PCB-PTH.drl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]
2024-02-07 Added BOM file
    [Liubomir_Stanev_project-B_Courtyard.gbr, Liubomir_Stanev_project-B_Cu.gbr, Liubomir_Stanev_project-B_Fab.gbr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]
2024-02-10 Some software additions
    [Liubomir_Stanev_project.kicad_pcb]
2024-02-15 Flask and esp32 updated
2024-02-16 Slight corrections in the software
    [flask_integration.ino]
2024-02-20 Added Mechanical details
    [BigBox.stl, Dist.vtulka.stl, G-figure.stl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]
